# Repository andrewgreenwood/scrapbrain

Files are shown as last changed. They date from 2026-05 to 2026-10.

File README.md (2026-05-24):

# "Scrap Brain"
YM2612-based synth controlled by a couple of ATmega328 chips with multiplexed analog inputs and an Adafruit touchscreen.

Contains 2 Arduino projects:
- "panel" provides a touchscreen UI and handles potentiometer readings, merging these with incoming MIDI messages
- "voice" controls the YM2612, responding to MIDI messages (either passed thru or sent by "panel")

The front panels were created in Lightburn and designed for Kitronik opaque black frosted perspex sheets.
I found it useful to burn off some of the material on the back of the panels, behind the jacks and pots.

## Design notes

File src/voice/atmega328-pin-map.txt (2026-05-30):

Pin map (atmega328):
0   Serial RX (MIDI in), also connected to FTDI TX
1   Serial TX, connected to FTDI RX
2   YM2612 D2
3   YM2612 clock
4   YM2612 D4
5   YM2612 D5
6   YM2612 D6
7   YM2612 D7
8   YM2612 D0
9   YM2612 D1
10  Op2 panel mod LED
11  YM2612 D3
12  Op3 panel mod LED
13  Op1 panel mod LED
A0  YM2612 ~IC
A1  YM2612 ~CS
A2  YM2612 ~WR
A3  YM2612 ~RD
A4  YM2612 A0
A5  YM2612 A1

Port bit masks corresponding to YM2612 data pins:
PORTB &= ~0x0b      // 00001011
PORTD &= ~0xf4      // 11110100
PORTB |= data & 0x0b
PORTD |= data & 0xf4

Split is necessary to accommodate UART and YM2612 clock

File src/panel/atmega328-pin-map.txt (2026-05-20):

Pin map (atmega328):
0   Serial RX (MIDI in), also connected to FTDI TX
1   Serial TX (MIDI out), also connected to FTDI RX
2   Display TCS
3   Display DC
4   Mux S0
5   Mux S1
6   Mux S2
7   Mux S3 (only for 16-channel)
8   -
9   Display backlight
10  -
11  SPI MOSI (for touchscreen)
12  SPI MISO (for touchscreen)
13  SPI SCK (for touchscreen)
A0  Mux C COM
A1  Mux A COM
A2  Mux B COM
A3  Mux D COM (main panel)
A4  I2C SDA (for touchscreen)
A5  I2C SCL (for touchscreen)

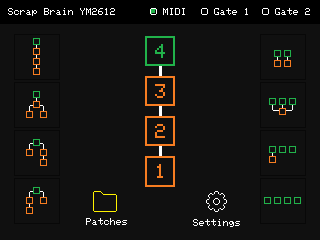
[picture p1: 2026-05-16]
design/Main Page.png

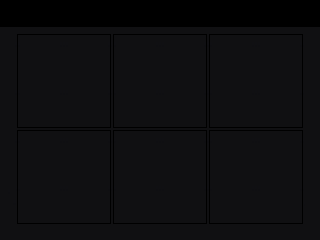
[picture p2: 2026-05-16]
design/Big Button Template.png

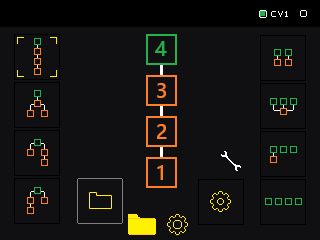
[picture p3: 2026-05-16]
design/Graphics.png

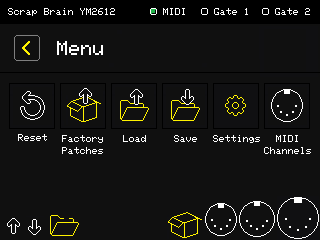
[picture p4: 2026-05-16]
design/Load Save.png

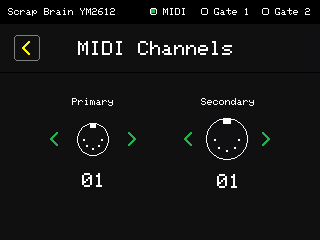
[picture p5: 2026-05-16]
design/Settings.png

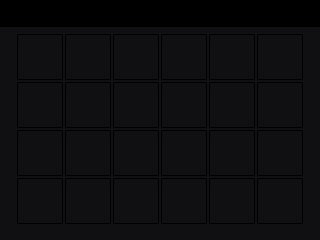
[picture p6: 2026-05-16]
design/Small Button Template.png

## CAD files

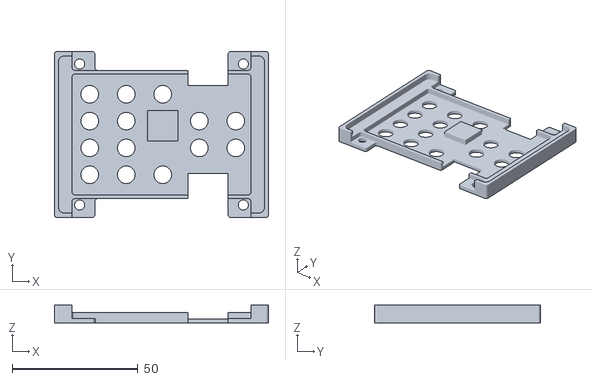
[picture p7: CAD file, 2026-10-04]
panels/Adafruit TFT Mount Back.stl
85.0 x 66.0 x 7.00

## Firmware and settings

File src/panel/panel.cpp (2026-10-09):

/*
    SCRAP BRAIN - YM2612 Hardware Synth - Panel
    Author: Andrew Greenwood
*/

// Debugging options
#define WITH_ASSERT             0
#define WITH_HOTSPOT_OUTLINE    0
#define WITH_DEBUG_PAGE         1

#define DISPLAY_TCS_PIN         2
#define DISPLAY_DC_PIN          3
#define GATE_CV_PIN             8
#define DISPLAY_BACKLIGHT_PIN   9
#define CV_ADC_CS_PIN           10

#define MUX_S0_PIN              4
#define MUX_S1_PIN              5
#define MUX_S2_PIN              6
#define MUX_S3_PIN              7

#define MAIN_MUX_COM_PIN        A3
#define MUX_1_COM_PIN           A1
#define MUX_2_COM_PIN           A2
#define MUX_3_COM_PIN           A0

// These are what the Voice microcontroller expects
#define MIDI_SEND_CHANNEL       1
#define CV_SEND_CHANNEL         2

#include <Arduino.h>

#ifdef MOCK_ARDUINO
#include "mockscreen.h"
#else
#include <EEPROM.h>
#include <Adafruit_ILI9341.h>
#include <Adafruit_FT6206.h>
#include <MIDI.h>
#include <MCP3XXX.h>
#endif

#include "panelkit.h"
#include "graphics.h"
#include "common.h"
#include "debug.h"

#ifdef MOCK_ARDUINO
MockScreen screen(240, 320);
MockTouchScreen touchscreen;
#else
struct MidiSettings : public midi::DefaultSettings {
    static const unsigned SysExMaxSize = 1;
    static const long BaudRate = 31250;
};
midi::SerialMIDI<HardwareSerial, MidiSettings> serialMIDI(Serial);
midi::MidiInterface<midi::SerialMIDI<HardwareSerial, MidiSettings>, MidiSettings> MIDI((midi::SerialMIDI<HardwareSerial, MidiSettings>&)serialMIDI);
Adafruit_ILI9341 screen(DISPLAY_TCS_PIN, DISPLAY_DC_PIN);
Adafruit_FT6206 touchscreen;
MCP3002 adc;
#endif

#define EEPROM_SETTINGS_OFFSET  0x000
#define EEPROM_PATCHES_OFFSET   sizeof(settings)

#define EEPROM_SIGNATURE    0xa9

struct Settings {
    uint8_t signature;
    uint8_t midi_channel;
} settings;

enum ControlIndex {
    // Mux A
    Op1_Sustain_ControlIndex = 0,
    Op1_Decay2_ControlIndex,
    Op1_Release_ControlIndex,
    Op1_AMStart_ControlIndex,
    Op1_Level_ControlIndex,
    Op1_Start_ControlIndex,
    Op1_Velocity_ControlIndex,
    Op1_EnvScale_ControlIndex,
    Op1_Detune_ControlIndex,
    Op1_Decay1_ControlIndex,
    Op1_FreqX_ControlIndex,
    Op1_Attack_ControlIndex,
    Op2_Attack_ControlIndex,
    Op2_Detune_ControlIndex,
    Op2_Decay1_ControlIndex,
    Op2_FreqX_ControlIndex,

    // Mux B
    Op2_Sustain_ControlIndex,
    Op2_Decay2_ControlIndex,
    Op2_Release_ControlIndex,
    Op2_AMStart_ControlIndex,
    Op2_Level_ControlIndex,
    Op2_Start_ControlIndex,
    Op2_Velocity_ControlIndex,
    Op2_EnvScale_ControlIndex,
    Op3_Sustain_ControlIndex,
    Op3_Decay2_ControlIndex,
    Op3_Release_ControlIndex,
    Op3_AMStart_ControlIndex,
    Op3_Level_ControlIndex,
    Op3_Start_ControlIndex,
    Op3_Velocity_ControlIndex,
    Op3_EnvScale_ControlIndex,

    // Mux C
    Op4_Sustain_ControlIndex,
    Op4_Decay2_ControlIndex,
    Op4_Release_ControlIndex,
    Op4_AMStart_ControlIndex,
    Op4_Level_ControlIndex,
    Op4_Start_ControlIndex,
    Op4_Velocity_ControlIndex,
    Op4_EnvScale_ControlIndex,
    Op3_Attack_ControlIndex,
    Op3_Detune_ControlIndex,
    Op3_Decay1_ControlIndex,
    Op3_FreqX_ControlIndex,
    Op4_FreqX_ControlIndex,
    Op4_Attack_ControlIndex,
    Op4_Detune_ControlIndex,
    Op4_Decay1_ControlIndex,

    // Mux D
    UNUSED1_ControlIndex,
    UNUSED2_ControlIndex,
    Op1_Feedback_ControlIndex,
    UNUSED3_ControlIndex,
    LFORate_ControlIndex,
    AMDepth_ControlIndex,
    PMStart_ControlIndex,
    PMDepth_ControlIndex,

    NumberOfPots,

    // Additional controls that aren't physical pots
    Algorithm_ControlIndex = NumberOfPots,

    NumberOfControls
};

const int8_t control_index_to_midi_controller_map[NumberOfControls] PROGMEM = {
    Op1_Sustain_MidiController,
    Op1_Decay2_MidiController,
    Op1_Release_MidiController,
    Op1_AMStart_MidiController,
    Op1_Level_MidiController,
    Op1_Start_MidiController,
    Op1_Velocity_MidiController,
    Op1_EnvScale_MidiController,
    Op1_Detune_MidiController,
    Op1_Decay1_MidiController,
    Op1_FreqX_MidiController,
    Op1_Attack_MidiController,
    Op2_Attack_MidiController,
    Op2_Detune_MidiController,
    Op2_Decay1_MidiController,
    Op2_FreqX_MidiController,
    Op2_Sustain_MidiController,
    Op2_Decay2_MidiController,
    Op2_Release_MidiController,
    Op2_AMStart_MidiController,
    Op2_Level_MidiController,
    Op2_Start_MidiController,
    Op2_Velocity_MidiController,
    Op2_EnvScale_MidiController,
    Op3_Sustain_MidiController,
    Op3_Decay2_MidiController,
    Op3_Release_MidiController,
    Op3_AMStart_MidiController,
    Op3_Level_MidiController,
    Op3_Start_MidiController,
    Op3_Velocity_MidiController,
    Op3_EnvScale_MidiController,
    Op4_Sustain_MidiController,
    Op4_Decay2_MidiController,
    Op4_Release_MidiController,
    Op4_AMStart_MidiController,
    Op4_Level_MidiController,
    Op4_Start_MidiController,
    Op4_Velocity_MidiController,
    Op4_EnvScale_MidiController,
    Op3_Attack_MidiController,
    Op3_Detune_MidiController,
    Op3_Decay1_MidiController,
    Op3_FreqX_MidiController,
    Op4_FreqX_MidiController,
    Op4_Attack_MidiController,
    Op4_Detune_MidiController,
    Op4_Decay1_MidiController,
    -1,
    -1,
    Op1_Feedback_MidiController,
    -1,
    LFORate_MidiController,
    AMDepth_MidiController,
    PMStart_MidiController,
    PMDepth_MidiController,
    Algorithm_MidiController
};

#define CONTROL_CASE(name)      case name##_MidiController: return name##_ControlIndex;
#define OP_CONTROL_CASE(name)   CONTROL_CASE(Op1_##name) \
                                CONTROL_CASE(Op2_##name) \
                                CONTROL_CASE(Op3_##name) \
                                CONTROL_CASE(Op4_##name)

int8_t midiControllerToControlIndex(int8_t midi_controller)
{
    switch (midi_controller) {
        CONTROL_CASE(LFORate)
        CONTROL_CASE(Algorithm)
        CONTROL_CASE(AMDepth)
        CONTROL_CASE(PMDepth)
        OP_CONTROL_CASE(AMStart)
        OP_CONTROL_CASE(Level)
        OP_CONTROL_CASE(Velocity)
        OP_CONTROL_CASE(Start)
        OP_CONTROL_CASE(FreqX)
        OP_CONTROL_CASE(Detune)
        CONTROL_CASE(Op1_Feedback)
        CONTROL_CASE(PMStart)
        OP_CONTROL_CASE(Attack)
        OP_CONTROL_CASE(Decay1)
        OP_CONTROL_CASE(Sustain)
        OP_CONTROL_CASE(Decay2)
        OP_CONTROL_CASE(Release)
        OP_CONTROL_CASE(EnvScale)
        default:    return -1;
    };
}

#undef CONTROL_CASE
#undef OP_CONTROL_CASE

int8_t controlIndexToMidiController(int8_t control_index)
{
    if ((control_index < 0) || (control_index >= NumberOfControls))
        return -1;

    return (int8_t)pgm_read_byte(&control_index_to_midi_controller_map[control_index]);
}

// Most recently loaded or saved patch (-1 for none)
#define NO_PATCH    -1
int8_t selected_patch = NO_PATCH;

// TODO: Pack
struct Patch {
    uint8_t controls[NumberOfControls];
    uint8_t reserved[64 - NumberOfControls];    // pad to 64 bytes length
};

// Current control values (loaded from patch, overridden by MIDI or panel)
uint8_t effective_control_values[NumberOfControls];

// Number of mux channels is (3x16)+8 == 56 (some are unused)
#define POT_READING_BUFFER_SIZE     4
uint8_t pot_readings[NumberOfPots][POT_READING_BUFFER_SIZE];
uint8_t previous_pot_readings[NumberOfPots];
uint8_t pot_reading_index = 0;

void updateDebugControlDisplay(uint8_t control_index);

// Send current value for a control
void sendControlValue(uint8_t control_index)
{
    int8_t midi_controller = controlIndexToMidiController(control_index);
    ASSERT(midi_controller != -1);
#if !defined(MOCK_ARDUINO)
    MIDI.sendControlChange(midi_controller, effective_control_values[control_index], MIDI_SEND_CHANNEL);
#endif
}

// Update the current value for a control and send it
void setControlValue(uint8_t control_index, uint8_t value, bool force_send = false)
{
    ASSERT(control_index < NumberOfControls);
    ASSERT(value < 0x80);

    if ((effective_control_values[control_index] == value) && (!force_send)) return;

    effective_control_values[control_index] = value;
    sendControlValue(control_index);

#if WITH_DEBUG_PAGE == 1
    updateDebugControlDisplay(control_index);
#endif
}

static void selectMuxChannel(uint8_t channel)
{
#if !defined(MOCK_ARDUINO)
    PORTD &= 0x0f;
    PORTD |= channel << 4;
#endif
}

uint8_t getMostCommonPotReading(uint8_t pot_index)
{
    uint8_t most_popular = 0;
    int most_popular_count = 0;

    for (int i = 0; i < POT_READING_BUFFER_SIZE; ++ i) {
        int value = pot_readings[pot_index][i];
        int count = 0;
        
        for (int j = 0; j < POT_READING_BUFFER_SIZE; ++ j) {
            if (pot_readings[pot_index][j] == value) {
                ++ count;
            }
        }

        if (count > most_popular_count) {
            most_popular_count = count;
            most_popular = value;
        }
    }

    return most_popular;
}

// Re-reads all pots (does not affect algorithm)
void resetControls()
{
    // Each read is preceded by a dummy read to try to improve stability
    for (int i = 0; i < POT_READING_BUFFER_SIZE; ++ i) {
        for (int mux_channel = 0; mux_channel < 16; ++ mux_channel) {
            selectMuxChannel(mux_channel);
#if !defined(MOCK_ARDUINO)
            analogRead(MUX_1_COM_PIN);
            pot_readings[mux_channel][i] = analogRead(MUX_1_COM_PIN) >> 2;
            analogRead(MUX_2_COM_PIN);
            pot_readings[16 + mux_channel][i] = analogRead(MUX_2_COM_PIN) >> 2;
            analogRead(MUX_3_COM_PIN);
            pot_readings[32 + mux_channel][i] = analogRead(MUX_3_COM_PIN) >> 2;
            if (mux_channel < 8) {
                analogRead(MAIN_MUX_COM_PIN);
                pot_readings[48 + mux_channel][i] = analogRead(MAIN_MUX_COM_PIN) >> 2;
            }
#endif
        }
    }

    // Commit the pot readings
    for (int i = 0; i < NumberOfPots; ++ i) {
        uint8_t value = getMostCommonPotReading(i);
        previous_pot_readings[i] = value;
        setControlValue(i, value >> 1, true);
    }
}



//
// The title bar and MIDI indicator state
//
class TopBar: public Panel {
    public:
        TopBar(UI &ui)
        : Panel(ui, 0, 0, 320, 24) { }

        virtual ~TopBar() { }

        void setMidiIndicatorState(bool state)
        {
            int16_t x = 273;

            if (state) {
                drawGraphic(GRAPHIC_GREEN_INDICATOR, x, 9);
            } else {
                setColour(BACKGROUND_COLOUR);
                fillRectangle(x, 9, 5, 5);
            }
        }

        void setGateIndicatorState(bool state)
        {
            int16_t x = 212;

            if (state) {
                drawGraphic(GRAPHIC_GREEN_INDICATOR, x, 9);
            } else {
                setColour(BACKGROUND_COLOUR);
                fillRectangle(x, 9, 5, 5);
            }
        }

    private:
        virtual void draw()
        {
            fill(TOPBAR_COLOUR);
            setTextSize(1);
            setColour(COLOUR_WHITE);

            // Title
            setCursor(12, 8);
            print(F("Scrap Brain YM2612"));

            // Gate CV indicator
            drawGraphic(GRAPHIC_INDICATOR_OUTLINE, 211, 8);
            setCursor(224, 8);
            print(F("Gate"));

            // MIDI indicator
            drawGraphic(GRAPHIC_INDICATOR_OUTLINE, 272, 8);
            setCursor(285, 8);
            print(F("MIDI"));
        }

        virtual void onTouchEvent(TouchEventType type, uint8_t hotspot_id, int16_t x, int16_t y) { }

        virtual void process() { }
};

class Page;

class Pager {
    friend class Page;

    public:
        Pager(UI &ui, int16_t x, int16_t y, int16_t width, int16_t height)
        : m_ui(ui), m_x(x), m_y(y), m_width(width), m_height(height),
          m_current_page(NULL)
        {
        }

        virtual ~Pager()
        {
        }

        void setPage(Page &page);

        bool isCurrentPage(Page &page)
        { return m_current_page == &page; }

    private:
        UI &m_ui;
        int16_t m_x;
        int16_t m_y;
        int16_t m_width;
        int16_t m_height;
        Page *m_current_page;
};

class Page: public Panel {
    friend class Pager;

    public:
        Page(Pager &pager)
        : Panel(pager.m_ui, pager.m_x, pager.m_y, pager.m_width, pager.m_height),
          m_is_active(false), m_number_of_hotspots(0), m_hotspots(NULL) { }

        virtual ~Page() { }

        bool isActive()
        { return m_is_active; }

    protected:
        virtual void onEnter() = 0;
        virtual void onLeave() = 0;

        virtual void setHotspots(uint16_t count, const Hotspot hotspots[])
        {
            m_number_of_hotspots = count;
            m_hotspots = hotspots;
        }

    private:
        virtual void draw() { }

        bool m_is_active;
        int16_t m_number_of_hotspots;
        const Hotspot *m_hotspots;
};

void Pager::setPage(Page &page)
{
    if (m_current_page) {
        m_current_page->hide();
        m_current_page->onLeave();
        m_current_page->m_is_active = false;
    }
    m_current_page = &page;
    page.Panel::setHotspots(page.m_number_of_hotspots, page.m_hotspots);
    m_current_page->m_is_active = true;
    m_current_page->onEnter();
    m_current_page->show();
}

class NotificationPage: public Page {
    public:
        NotificationPage(Pager &pager)
        : Page(pager), m_colour(COLOUR_WHITE), m_message(NULL), m_expiry_time(0), m_animate_start_time(0), m_next_page(NULL)
        { }

        void notify(uint16_t colour, const __FlashStringHelper *message, uint16_t duration, Page &next_page)
        {
            m_colour = colour;
            m_message = message;
            m_expiry_time = millis() + duration;
            m_next_page = &next_page;
        }

    private:
        virtual void onEnter()
        { m_animate_start_time = millis(); }

        virtual void onLeave() { }

        virtual void draw()
        {
            uint16_t x = (width() / 2) - ((strlen_P(reinterpret_cast<PGM_P>(m_message)) * 12) / 2);
            if (millis() - m_animate_start_time < 100) {
                setColour(scaleColour(m_colour, 0x80));
            } else {
                setColour(m_colour);
            }
            setTextSize(2);
            setCursor(x, (height() / 2) - 14);
            print(m_message);
        }

        virtual void onTouchEvent(TouchEventType type, uint8_t hotspot_id, int16_t x, int16_t y) { }

        virtual void process();

        uint16_t m_colour;
        const __FlashStringHelper *m_message;
        unsigned long m_expiry_time;
        unsigned long m_animate_start_time;
        Page *m_next_page;
};

// TODO: Move these
#define MIN_PATCH_INDEX             0
#define MAX_PATCH_INDEX             19

#define MIN_USER_PATCH_INDEX        0
#define MAX_USER_PATCH_INDEX        9

#define MIN_FACTORY_PATCH_INDEX     10
#define MAX_FACTORY_PATCH_INDEX     19

#define PAGE_HEADER_Y   11
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
void loop()
{
    unsigned long pot_read_time_start = millis();

    for (int mux_channel = 0; mux_channel < 16; ++ mux_channel) {
        selectMuxChannel(mux_channel);

        // TODO: Figure out why analog pins aren't defined for mock Arduino
#if !defined(MOCK_ARDUINO)
        // Each read is preceded by a dummy read to try to improve stability
        analogRead(MUX_1_COM_PIN);
        pot_readings[mux_channel][pot_reading_index] = analogRead(MUX_1_COM_PIN) >> 2;
        processMidi();
        processCV();
        processTouchscreenInput();

        analogRead(MUX_2_COM_PIN);
        pot_readings[16 + mux_channel][pot_reading_index] = analogRead(MUX_2_COM_PIN) >> 2;
        processMidi();
        processCV();
        processTouchscreenInput();

        analogRead(MUX_3_COM_PIN);
        pot_readings[32 + mux_channel][pot_reading_index] = analogRead(MUX_3_COM_PIN) >> 2;
        processMidi();
        processCV();
        processTouchscreenInput();

        if (mux_channel < 8) {
            analogRead(MAIN_MUX_COM_PIN);
            pot_readings[48 + mux_channel][pot_reading_index] = analogRead(MAIN_MUX_COM_PIN) >> 2;
        }
        processMidi();
        processCV();

#endif
        processTouchscreenInput();
    }

    processTouchscreenInput();

#if WITH_DEBUG_PAGE == 1
    if (pager.isCurrentPage(debug_page)) {
        debug_page.updatePotReadTimeMeasurement(millis() - pot_read_time_start);
    }
#endif

    ++ pot_reading_index;
    pot_reading_index %= POT_READING_BUFFER_SIZE;

    for (int i = 0; i < NumberOfPots; ++ i) {
        uint8_t value = getMostCommonPotReading(i);
        if (abs((int16_t)value - (int16_t)previous_pot_readings[i]) > 1) {
            previous_pot_readings[i] = value;
            setControlValue(i, value >> 1);
        }
    }

    if ((last_midi_event_time > 0) && (millis() - last_midi_event_time >= MIDI_INDICATOR_BLINK_TIME)) {
        top_bar.setMidiIndicatorState(false);
        last_midi_event_time = 0;
    }

    ui.process();
}

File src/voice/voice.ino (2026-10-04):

/*
    SCRAP BRAIN - YM2612 Hardware Synth - Panel
    Author: Andrew Greenwood

    MIDI is received on channels 1 and 2
    The panel microcontroller may receive external MIDI on a configured
    MIDI input channel but will forward it on channel 1. Channel 2 is
    used for handling CV inputs from the panel microcontroller.

    All audio output goes to both L/R channels of the YM2612.
*/

#include <MIDI.h>
#include "common.h"
#include "synth.h"

#define YM2612_CLOCK_PIN    3
#define YM2612_IC_PIN       A0
#define YM2612_CS_PIN       A1
#define YM2612_WR_PIN       A2
#define YM2612_RD_PIN       A3
#define YM2612_A0_PIN       A4
#define YM2612_A1_PIN       A5

// YM2612 data pins are split between PORTB and PORTD
#define YM2612_DATA_PORTB_BITMASK   0x0b
#define YM2612_DATA_PORTD_BITMASK   (~YM2612_DATA_PORTB_BITMASK)

// PORTB bits for LED patterns indicating which operators are modulators
#define OP_MOD_LED_PORTB_BITMASK    0x34    // 00110100
#define OP1_MOD_LED_PORTB_BIT       bit(5)  // 00100000
#define OP2_MOD_LED_PORTB_BIT       bit(2)  // 00000100
#define OP3_MOD_LED_PORTB_BIT       bit(4)  // 00010000

void setOperatorPanelLEDPattern(uint8_t algorithm)
{
    static const uint8_t led_bit_map[8] = {
        OP1_MOD_LED_PORTB_BIT | OP2_MOD_LED_PORTB_BIT | OP3_MOD_LED_PORTB_BIT,
        OP1_MOD_LED_PORTB_BIT | OP2_MOD_LED_PORTB_BIT | OP3_MOD_LED_PORTB_BIT,
        OP1_MOD_LED_PORTB_BIT | OP2_MOD_LED_PORTB_BIT | OP3_MOD_LED_PORTB_BIT,
        OP1_MOD_LED_PORTB_BIT | OP2_MOD_LED_PORTB_BIT | OP3_MOD_LED_PORTB_BIT,
        OP1_MOD_LED_PORTB_BIT | OP3_MOD_LED_PORTB_BIT,
        OP1_MOD_LED_PORTB_BIT,
        OP1_MOD_LED_PORTB_BIT,
        0
    };

    if (algorithm < 8) {
        PORTB = (PORTB & ~OP_MOD_LED_PORTB_BITMASK) | led_bit_map[algorithm];
    }
}

float noteToPitch(float note)
{
    int offset = note - 72;
    return (616 * pow(2, (float)offset / 12));
}

unsigned short noteToYM2612Frequency(float note)
{
    unsigned char block = 0;
    unsigned short frequency;
    float offset = note - 94;

    if (offset >= 1) {
        block = offset / 12;
        offset -= 12 * block;
    }

    block += 4;

    frequency = (978 * pow(2, offset / 12));

    return ((unsigned short)block << 11) | frequency;
}

namespace YM2612 {
    struct Controls {
        Controls()
        : algorithm(7), op1_feedback(0), left_output_enable(1), right_output_enable(1),
          am_sensitivity(0), pm_sensitivity(0), pm_start(0)
        {
            for (int op = 0; op < 4; ++ op) {
                operators[op].start = 0;
                operators[op].frequency_multiplier = 1;
                operators[op].detune = 0;
                operators[op].attack_rate = 31;
                operators[op].rate_scaling = 0;
                operators[op].decay1_rate = 0;
                operators[op].am_start = 0;
                operators[op].decay2_rate = 0;
                operators[op].release_rate = 15;
                operators[op].sustain_level = 0;
                operators[op].ssgeg_on = false;
                operators[op].ssgeg = 0;
                operators[op].velocity_to_level = 127;
                operators[op].level = 127;
            }
        };

        uint8_t algorithm               : 3;
        uint8_t op1_feedback            : 3;
        uint8_t left_output_enable      : 1;
        uint8_t right_output_enable     : 1;
        uint8_t am_sensitivity          : 2;
        uint8_t pm_sensitivity          : 3;
        uint8_t pm_start                : 7;

        struct {
            uint8_t start                   : 7;
            uint8_t frequency_multiplier    : 4;
            uint8_t detune                  : 3;
            uint8_t attack_rate             : 5;
            uint8_t rate_scaling            : 2;
            uint8_t decay1_rate             : 5;
            uint8_t am_start                : 7;
            uint8_t decay2_rate             : 5;
            uint8_t release_rate            : 4;
            uint8_t sustain_level           : 4;
            uint8_t ssgeg_on                : 1;
            uint8_t ssgeg                   : 3;
            uint8_t velocity_to_level       : 7;
            uint8_t level                   : 7;
        } operators[4];
    };

    enum GlobalRegister {
        LFO_GlobalRegister = 0x22,
        TimerAFrequencyHigh_GlobalRegister = 0x24,
        TimerAFrequencyLow_GlobalRegister = 0x25,
        TimerBFrequency_GlobalRegister = 0x26,
        Channel3ModeAndTimer_GlobalRegister = 0x27,
        Key_GlobalRegister = 0x28,
        DACOutput_GlobalRegister = 0x2a,
        DACEnable_GlobalRegister = 0x2b
    };

    enum ChannelRegister {
        Frequency_ChannelRegister = 0xa0,
        ALGO_FEED_ChannelRegister = 0xb0,
        L_R_AMS_PMS_ChannelRegister = 0xb4
    };

    static uint8_t pack_ALGO_FEED_Value(uint8_t algo, uint8_t feed)
    { return (algo & 0x7) | ((feed & 0x7) << 3); }

    static uint8_t pack_L_R_AMS_PMS_Value(uint8_t l, uint8_t r, uint8_t ams, uint8_t pms)
    { return (((l & 0x1) << 7) | ((r & 0x1) << 6) | ((ams & 0x3) << 4) | ((pms) & 0x7)); }

    enum OperatorRegister {
        MUL_DT_OperatorRegister = 0x30,
        TL_OperatorRegister = 0x40,
        AR_RS_OperatorRegister = 0x50,
        DR_AMON_OperatorRegister = 0x60,
        SR_OperatorRegister = 0x70,
        RR_SL_OperatorRegister = 0x80,
        SSGEG_OperatorRegister = 0x90,
    };

    static uint8_t pack_MUL_DT_Value(uint8_t mul, uint8_t dt)
    { return (mul & 0x0f) | ((dt & 0x7) << 4); }

    static uint8_t pack_AR_RS_Value(uint8_t ar, uint8_t rs)
    { return (ar & 0x1f) | ((rs & 0x3) << 6); }

    static uint8_t pack_DR_AMON_Value(uint8_t dr, bool amon)
    { return (dr & 0x1f) | (amon << 7); }

    static uint8_t pack_RR_SL_Value(uint8_t rr, uint8_t sl)
    { return (rr & 0xf) | ((sl & 0xf) << 4); }

    // TODO: Test
    /*
    uint8_t read()
    {
        uint8_t data;

        digitalWrite(YM2612_CS_PIN, LOW);
        delayMicroseconds(1);

        DDRB &= ~YM2612_DATA_PORTB_BITMASK;
        DDRD &= ~YM2612_DATA_PORTD_BITMASK;

        digitalWrite(YM2612_A0_PIN, LOW);
        digitalWrite(YM2612_A1_PIN, LOW);

        delayMicroseconds(1);
        digitalWrite(YM2612_RD_PIN, LOW);
        delayMicroseconds(5);

        data  = PORTB & YM2612_DATA_PORTB_BITMASK;
        data |= PORTD & YM2612_DATA_PORTD_BITMASK;

        digitalWrite(YM2612_RD_PIN, HIGH);
        delayMicroseconds(5);

        digitalWrite(YM2612_CS_PIN, HIGH);

        return data;
    }
    */

    // Wait for YM2612 busy bit to be clear
    // (doesn't work currently)
    void wait()
    {
        //while (Read() & 0x80) { }
    }

    void write(uint8_t address, uint8_t data)
    {
        wait();

        digitalWrite(YM2612_CS_PIN, LOW);
        delayMicroseconds(1);

        digitalWrite(YM2612_A0_PIN, address & 2 ? HIGH : LOW);
        digitalWrite(YM2612_A1_PIN, address & 1 ? HIGH : LOW);
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

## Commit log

2026-05-17 Fix NULL pointer and incorrect panel dereference, add error display
    [panel.cpp]
2026-05-20 Split graphics definitions into a separate file. Document pin map
2026-05-21 Update algorithm, fix memory access issue
    [panel.cpp]
2026-05-21 Use correct MIDI channel. Fix algorithm display update.
    [panel.cpp]
2026-05-22 Send on correct channel
    [panel.cpp]
2026-05-22 Rework of old voice microcontroller code
    [common.h, voice.ino]
2026-05-24 Use named MIDI controllers, implement PM start, other fixes
    [voice.ino]
2026-05-24 LEDs for indicating which operators are modulators
2026-05-30 Wire up IC pin
2026-10-03 Add main panel jacks for Gate, V/Oct, Velocity and Out, along with audio level LED
2026-10-04 CV handling. "Panel" controller no longer enables MIDI thru, but instead forwards MIDI data on channel 1, and sends its own messages on that channel as well (MIDI channel settings only determine what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
    Still some kinks with pitch and gate timing to work out though (sometimes there's a brief
    wrong pitch when gate goes high.)
    [panel.cpp, voice.ino]
2026-10-04 Add ADC library to dependencies
2026-10-04 Laser cutter design for thinning the back of the main panel. Updated TFT mount STL
    [Adafruit TFT Mount Back.stl]
2026-10-09 Scan CV inputs more frequently to avoid weird pitch stepping. Make velocity CV work.
    [panel.cpp]
